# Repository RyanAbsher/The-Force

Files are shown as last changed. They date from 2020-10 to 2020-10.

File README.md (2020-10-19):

# The-Force
 Raspberry Pi and Arduino Based Exhibit Show Controller
 
## Introduction
Shortly before we shut down operations due to Covid-19, one of the exhibits at my place of employment had a hardware failure. After we re-opened, due to financial hardships, we were unable
to cover the cost of having the exhibit repaired. It would require all new hardware as well as new software. I decided to see what I could do with the equipment on hand.

## Hardware
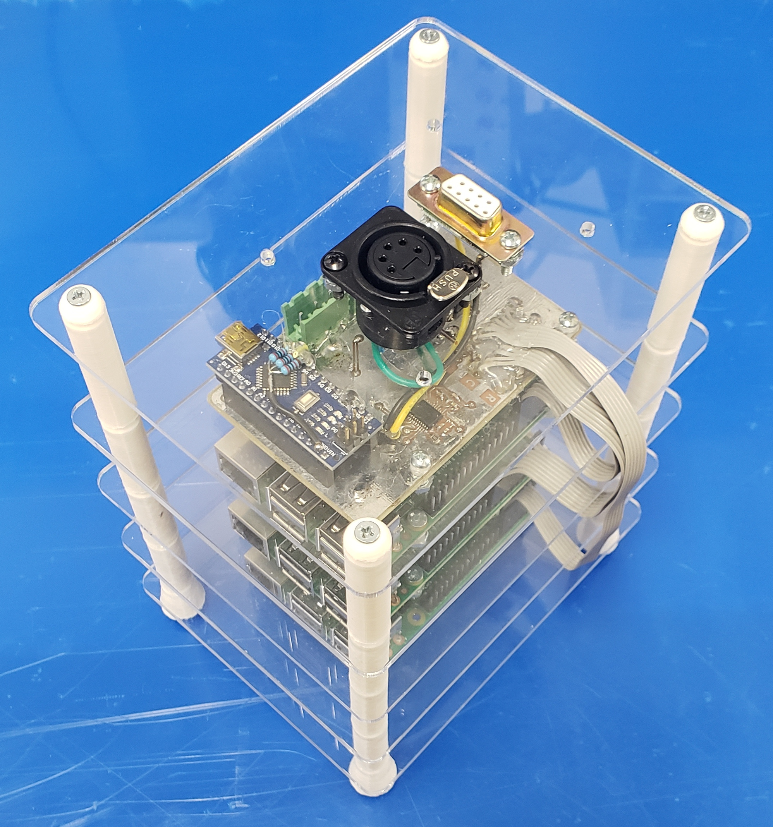
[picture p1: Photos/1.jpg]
PCB Render


The exhibit uses 3 synchronized monitors to show a video, uses multiple DMX512 controlled lights, has an RS-232 controlled timer, and has multiple audio outputs. I decided to use 3 Raspberry Pis and
an Arduino Nano to replicate the original hardware.

I designed and etched a PCB that would hold the Arduino, as well as acting as the connection point for all of the different pieces. Each RPi has a cable which connects to this board. The DMX and RS-232 cables also plug into this board.
I put all of the requisite hardware for each of these protocols onboard.

For simply asthetic reasons I made the board fit the same form factor and mounting holes as a Raspberry Pi.

I laser cut the acrylic shelves and 3D printed the white plastic stand-offs.

## Software
When the user presses the start button, a python program on the center RPi detects it. It then signals the other 2 RPis to start the show on it's command. The center RPi also signals the Arduino to start the 
timer and begin the light show.

The timings for the light show require many entries into the Arduino program, and was too complicated to keep up with. I ended up creating a python program to help with that. I created a simle psuedo-scripting language (3 whole commands!) that allows me to create the light show in a more human-readable format. The python program then takes this input from def.txt, does all the math, and outputs the raw timings into def.h which can be used directly by the arduino program.

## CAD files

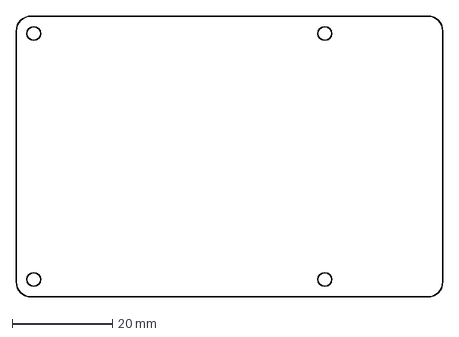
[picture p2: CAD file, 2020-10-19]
KiCAD/board_layout.dxf
85.0 x 56.0 mm

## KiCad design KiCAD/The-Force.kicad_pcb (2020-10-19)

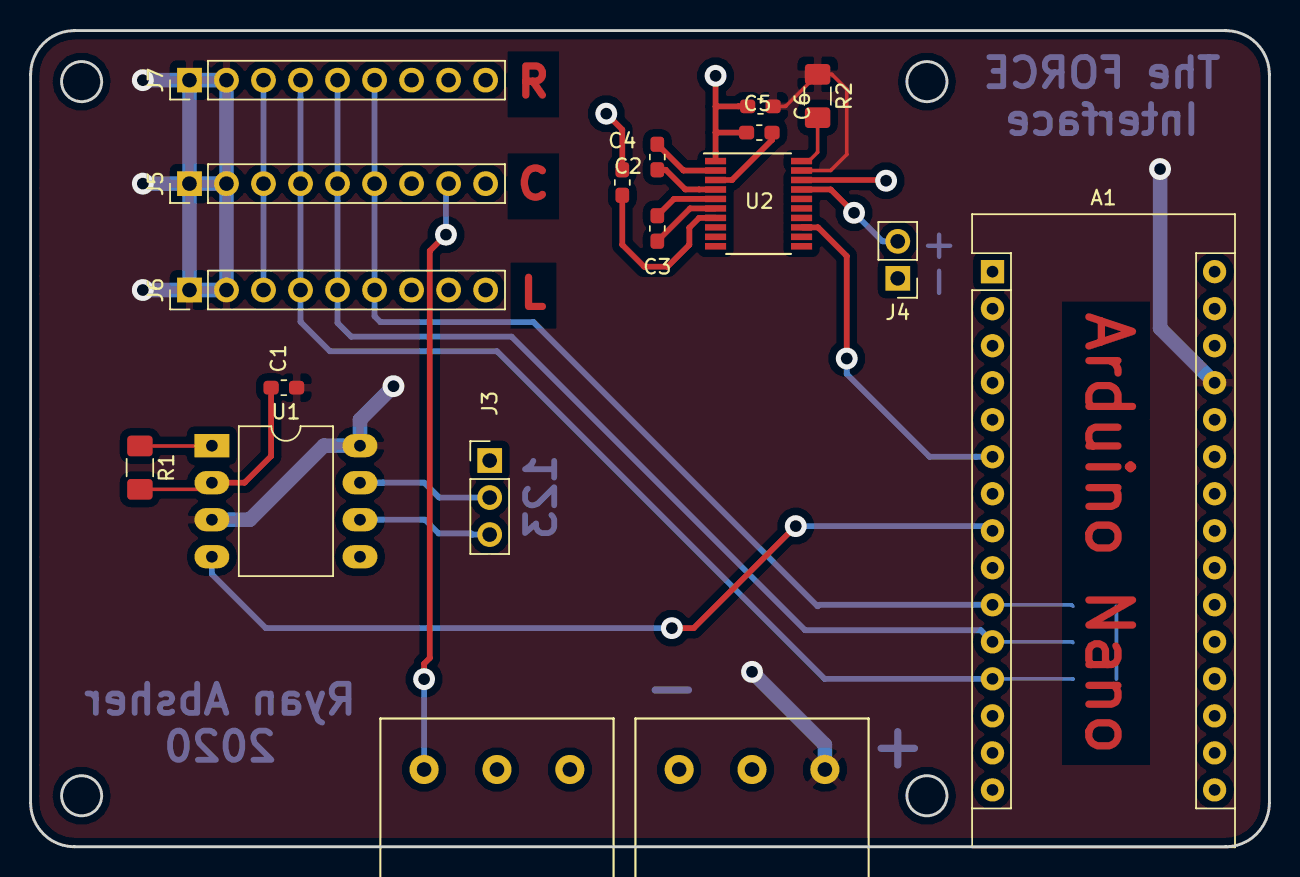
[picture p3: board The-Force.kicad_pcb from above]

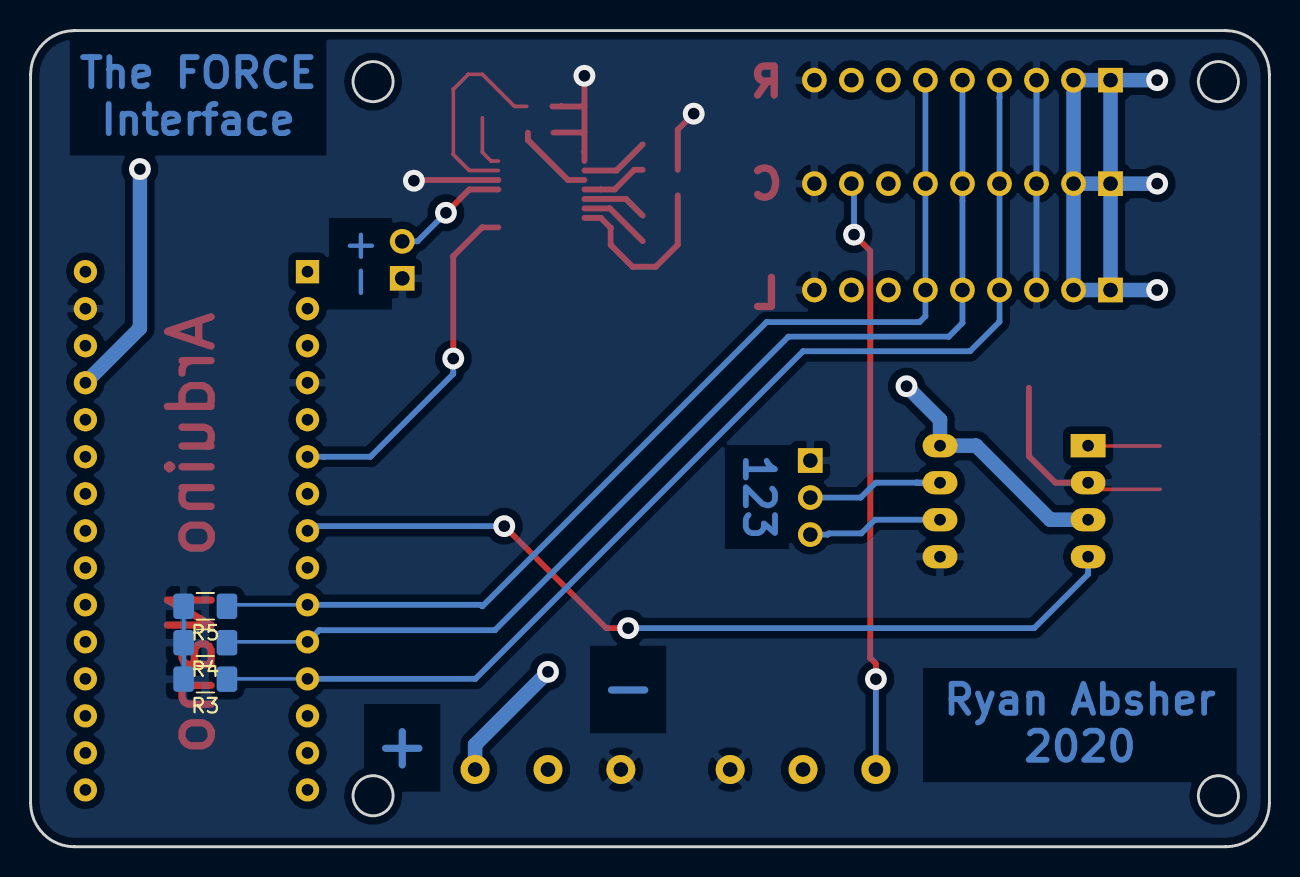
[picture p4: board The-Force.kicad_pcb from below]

Board: 2 copper layers, 85.0 x 56.0 mm, 21 parts (3 on the bottom side), 19 nets.

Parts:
A1: Arduino_Nano_v3.x; Arduino_Nano
C1, C6: 0.1uF; C_0603_1608Metric_Pad1.05x0.95mm_HandSolder
C2: 0.047uF; C_0603_1608Metric_Pad1.05x0.95mm_HandSolder
C3, C4, C5: 0.33uF; C_0603_1608Metric_Pad1.05x0.95mm_HandSolder
J1: Start Button; Terminal
J2: +5v In; Terminal
J3: XLR3_Ground; PinHeader_1x03_P2.54mm_Vertical
J4: To DB9; PinHeader_1x02_P2.54mm_Vertical
J5: RPi Center; PinHeader_1x09_P2.54mm_Vertical
J6: RPi Left; PinHeader_1x09_P2.54mm_Vertical
J7: RPi Right; PinHeader_1x09_P2.54mm_Vertical
R1: 100R; R_1206_3216Metric_Pad1.42x1.75mm_HandSolder
R2: 22k; R_1206_3216Metric_Pad1.42x1.75mm_HandSolder
R3, R4, R5: 20k; R_1206_3216Metric_Pad1.42x1.75mm_HandSolder
U1: SN75176AP; DIP-8_W10.16mm_LongPads
U2: MAX3222; TSSOP-20_4.4x6.5mm_P0.65mm

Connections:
+5V: A1.27, C1.2, C6.2, J2.3, J5.1, J5.2, J6.1, J6.2, J7.1, J7.2, R2.1, U1.3, U1.8, U2.19
/DMX/DMXA: J3.3, U1.6
/DMX/DMXB: J3.2, U1.7
/RS-232/RS232_OUT: J4.2, U2.17
/RS-232/V+: C5.2, U2.3
/START_BUTTON: J1.1, J5.8
DMX_DATA: A1.8, U1.4
GND: A1.4, A1.29, C1.1, C4.1, C5.1, C6.1, J1.3, J2.1, J3.1, J4.1, J5.3, J5.9, J6.3, J6.9, J7.3, J7.9, R1.2, R3.2, R4.2, R5.2, U1.2, U1.5, U2.1, U2.18
unnamed: C2.1, U2.4
unnamed: C2.2, U2.2
unnamed: C3.1, U2.6
unnamed: C3.2, U2.5
unnamed: C4.2, U2.7
unnamed: R1.1, U1.1
unnamed: R2.2, U2.20
RS_232_DATA: A1.6, U2.13
SHOW_SIGNAL_1: A1.12, J5.4, J6.4, J7.4, R3.1
SHOW_SIGNAL_2: A1.11, J5.5, J6.5, J7.5, R4.1
SHOW_SIGNAL_3: A1.10, J5.6, J6.6, J7.6, R5.1

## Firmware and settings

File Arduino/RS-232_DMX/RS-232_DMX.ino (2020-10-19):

// DmxSimple Library: http://code.google.com/p/tinkerit/
// RS-232 code adapted from https://www.arduino.cc/en/Tutorial/ArduinoSoftwareRS232

#include <ctype.h>
#include "showDef.h"
#include <DmxSimple.h>

//List of fixture addresses and number of channels to turn off for clearAll()
int fixtureList[2][7] = {{ 2, 7, 20, 47, 51, 72, 100},
                         { 3, 4, 3,  4,  4,  4,  4  }};

#define bit2400Delay 416
#define halfBit2400Delay 208
#define RS_232_TX 3

#define SHOW_SIGNAL1 9
#define SHOW_SIGNAL2 8
#define SHOW_SIGNAL3 7

byte tx = 3;
byte SWval;
byte running = 1;

int currentShowStep = 0;
unsigned long showTimer = 0;
int showStarted = 0;
unsigned long nextStepTime = 0;
int timerSet = 0;
int count = 0;

void setup()
{
  Serial.begin(115200);
  DmxSimple.usePin(5);
  DmxSimple.maxChannel(4);

  //Turn the sign on
  DmxSimple.write(31, 255);

  //Turn on the Button and button sign
  DmxSimple.write(90, 255);
  
  pinMode(tx, OUTPUT);
  digitalWrite(tx, HIGH);
  delay(2);

  //Serial.println("Ready to start");
  
}

void loop()
{

  //setTimer();
  if(digitalRead(SHOW_SIGNAL2) == HIGH)
  {
    if(timerSet == 0)
    {
      //Serial.println("Setting Timer");
      setTimer();
      timerSet = 1;
    }
  }
  if(digitalRead(SHOW_SIGNAL3) == HIGH)
  {
    // Run the show
    if(!showStarted)
    {
      //Serial.println("Starting Show");
      //Turn off the Button and button sign
      DmxSimple.write(90, 0);
      showStarted = 1;
      showTimer = millis();
    }
    else
    {
      nextStepTime = (startTime[currentShowStep]);
      nextStepTime = nextStepTime * 100;

      /*count += 1;
      if(count == 10000)
      {
      //Serial.print("Current Step: ");
      //Serial.print(currentShowStep);
      //Serial.print(" Next Step Time: ");
      //Serial.print(nextStepTime);
      //Serial.print(" Current Time: ");
      //Serial.println(millis() - showTimer);
      count = 0;
      };*/
      
      if(millis() - showTimer >= (nextStepTime))
      {
        //Serial.print("Fixture: ");
        //Serial.print(fixtureNumber[currentShowStep]);
        //Serial.print(" Value: ");
        Serial.println(sendValue[currentShowStep]);
        DmxSimple.write(fixtureNumber[currentShowStep], sendValue[currentShowStep]);
        if(currentShowStep < NUM_DEF)
        {
          currentShowStep += 1;
        };
      }
    }
    
  }
  else
  {
    //Stop the show
    if(showStarted)
    {
      //Turn on the Button and button sign
      DmxSimple.write(90, 255);
      showStarted = 0;
      clearAll();
      timerSet = 0;
      //Serial.println("Show Stopped");
      currentShowStep = 0;
    };
  }
}
//

// Send data to RS-232 bus
void SWprint(int data)
{
  byte mask;
  //startbit
  digitalWrite(tx,LOW);
  delayMicroseconds(bit2400Delay);
  for (mask = 0x01; mask>0; mask <<= 1) {
    if (data & mask){ // choose bit
     digitalWrite(tx,HIGH); // send 1
    }
    else{
     digitalWrite(tx,LOW); // send 0
    }
    delayMicroseconds(bit2400Delay);
  }
  //stop bit
  digitalWrite(tx, HIGH);
  delayMicroseconds(bit2400Delay);
}

//Set up the countdown timer
void setTimer()
{
  /*// Settings found at: http://www.ats-usa.com/pdf_manuals/354man3.pdf
  
  //Serial.println("Enter setting timer");
  
  SWprint(0x11); // Initialize
  
  SWprint(0x00); // Address
  
  SWprint(0x05); // Mode Setting
  
  SWprint(0x00); // Digit 0 (Leave 0)
  SWprint(0x00); // Digit 1 (Leave 0)
  SWprint(0x00); // Digit 2
  SWprint(0x00); // Digit 3
  SWprint(0x01); // Digit 4
  SWprint(0x07); // Digit 6
  
  SWprint(0x02); // Misc Settings
  */
}

// Blanks out all lights except the sign.
void clearAll()
{
  for(int f = 0; f <= 6; f++)
  {
    int startAddress = fixtureList[0][f];
    int endAddress = fixtureList[0][f] + fixtureList[1][f];
    for(int n = startAddress; n < endAddress; n++)
    {
         DmxSimple.write(n, 0);
    }
  }
}
